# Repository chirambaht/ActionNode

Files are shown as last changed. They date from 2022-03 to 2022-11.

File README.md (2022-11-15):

# Action Tracer Node
This repository supports the Action Tracer project which I undertook as part of my Masters Dissertation at the University of Cape Town in 2021 - 2022.

## What is Action Tracer?
This project aims to create a motion capture system based on the MPU-6050 IMU. This system is powered by a Raspberry Pi Zero W, which collects, processes and sends data, in real time, to a users device. 

Action Tracer differs from most systes due to its use of a 6-axes IMU and it's promise to deliver 30 frames per second with minimal latency over a Wi-Fi network. 

To see more on this project, please visit the main repository: [Action Tracer](https://github.com/chirambaht/Action-Tracer).
## Why a node?
To monitor each articulating joint, an IMU needs to be placed near by to capture its rotation. To help this, the design houses two 20mm wide slots that allow a strap to go through it and strap it to the area it is montoring. At this stage, this design shows a wired node but future plans involve turning this node wireless. One such implementation of this was attempted and can be found here: [Wireless Action Node](https://github.com/chirambaht/WirelessAction).
## Bill of Materials
| Comment | Designator | Footprint | LCSC |
|---|---|---|---|
| 0.1u | C2,C5 | C_0603_1608Metric | C14663 |
| 2.2n | C3 | C_0603_1608Metric | C1604  |
| 0.33u | C4 | C_0603_1608Metric | C1615  |
| Power | D1,D2 | LED_0603_1608Metric | C2286  |
| MPU-6050 | U1 | InvenSense_QFN-24_4x4mm_P0.5mm | C24112 |
| 10k | R1,R2 | R_0603_1608Metric | C25804 |
| 68 | R3,R4 | R_0603_1608Metric | C27592 |
| 10n | C1 | C_0603_1608Metric | C57112 |
| AMS1117-3.3 | U2 | SOT-223-3_TabPin2 | C6186  |
## Images
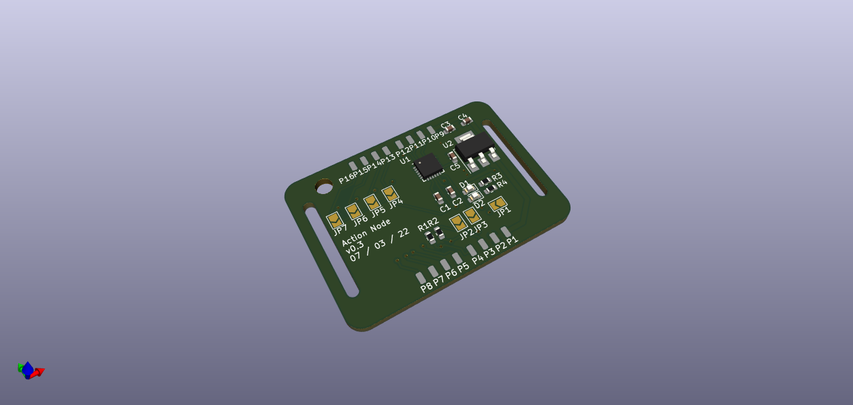
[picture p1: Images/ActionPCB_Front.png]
Front of the board The front of the Action Tracer Node.

A picture showing the front of the board. This will hold all the components used in this project. 
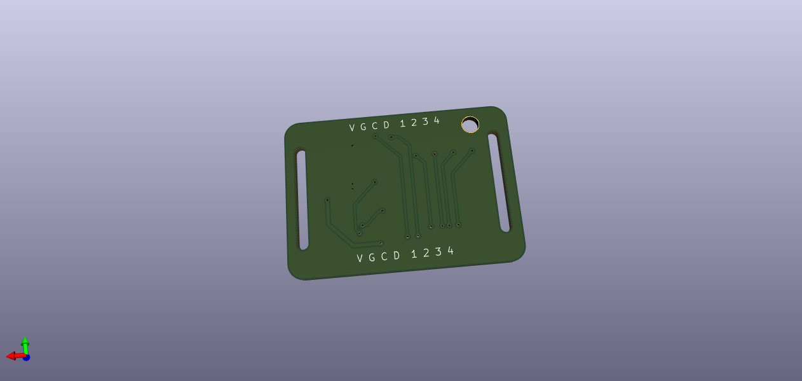
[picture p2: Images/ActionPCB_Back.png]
Back of the board The front of the Action Tracer Node.

The rear side of the board with markings for each of the connector lines, showing where they should be placed.
## Tools
This board was designed in KiCad 6.0.

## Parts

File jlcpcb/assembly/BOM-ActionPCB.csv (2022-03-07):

Comment | Designator | Footprint | LCSC
0.1u | C2,C5 | C_0603_1608Metric | C14663
2.2n | C3 | C_0603_1608Metric | C1604
0.33u | C4 | C_0603_1608Metric | C1615
Power | D1,D2 | LED_0603_1608Metric | C2286
MPU-6050 | U1 | InvenSense_QFN-24_4x4mm_P0.5mm | C24112
10k | R1,R2 | R_0603_1608Metric | C25804
68 | R3,R4 | R_0603_1608Metric | C27592
10n | C1 | C_0603_1608Metric | C57112
AMS1117-3.3 | U2 | SOT-223-3_TabPin2 | C6186
CH4 | P16 | SolderWirePad_1x01_SMD_1x2mm
CH3 | P15 | SolderWirePad_1x01_SMD_1x2mm
CH2 | P14 | SolderWirePad_1x01_SMD_1x2mm
CH1 | P13 | SolderWirePad_1x01_SMD_1x2mm
SDA | P12 | SolderWirePad_1x01_SMD_1x2mm
SCL | P11 | SolderWirePad_1x01_SMD_1x2mm
GND | P10 | SolderWirePad_1x01_SMD_1x2mm
VCC | P9 | SolderWirePad_1x01_SMD_1x2mm
CH4 | P8 | SolderWirePad_1x01_SMD_1x2mm
CH3 | P7 | SolderWirePad_1x01_SMD_1x2mm
CH2 | P6 | SolderWirePad_1x01_SMD_1x2mm
CH1 | P5 | SolderWirePad_1x01_SMD_1x2mm
SDA | P4 | SolderWirePad_1x01_SMD_1x2mm
SCL | P3 | SolderWirePad_1x01_SMD_1x2mm
GND | P2 | SolderWirePad_1x01_SMD_1x2mm
VCC | P1 | SolderWirePad_1x01_SMD_1x2mm
Jumper | JP7 | SolderJumper-2_P1.3mm_Open_TrianglePad1.0x1.5mm
Jumper | JP6 | SolderJumper-2_P1.3mm_Open_TrianglePad1.0x1.5mm
Jumper | JP5 | SolderJumper-2_P1.3mm_Open_TrianglePad1.0x1.5mm
Jumper | JP4 | SolderJumper-2_P1.3mm_Open_TrianglePad1.0x1.5mm
Jumper | JP3 | SolderJumper-2_P1.3mm_Open_TrianglePad1.0x1.5mm
Jumper | JP2 | SolderJumper-2_P1.3mm_Open_TrianglePad1.0x1.5mm
Jumper | JP1 | SolderJumper-2_P1.3mm_Open_TrianglePad1.0x1.5mm

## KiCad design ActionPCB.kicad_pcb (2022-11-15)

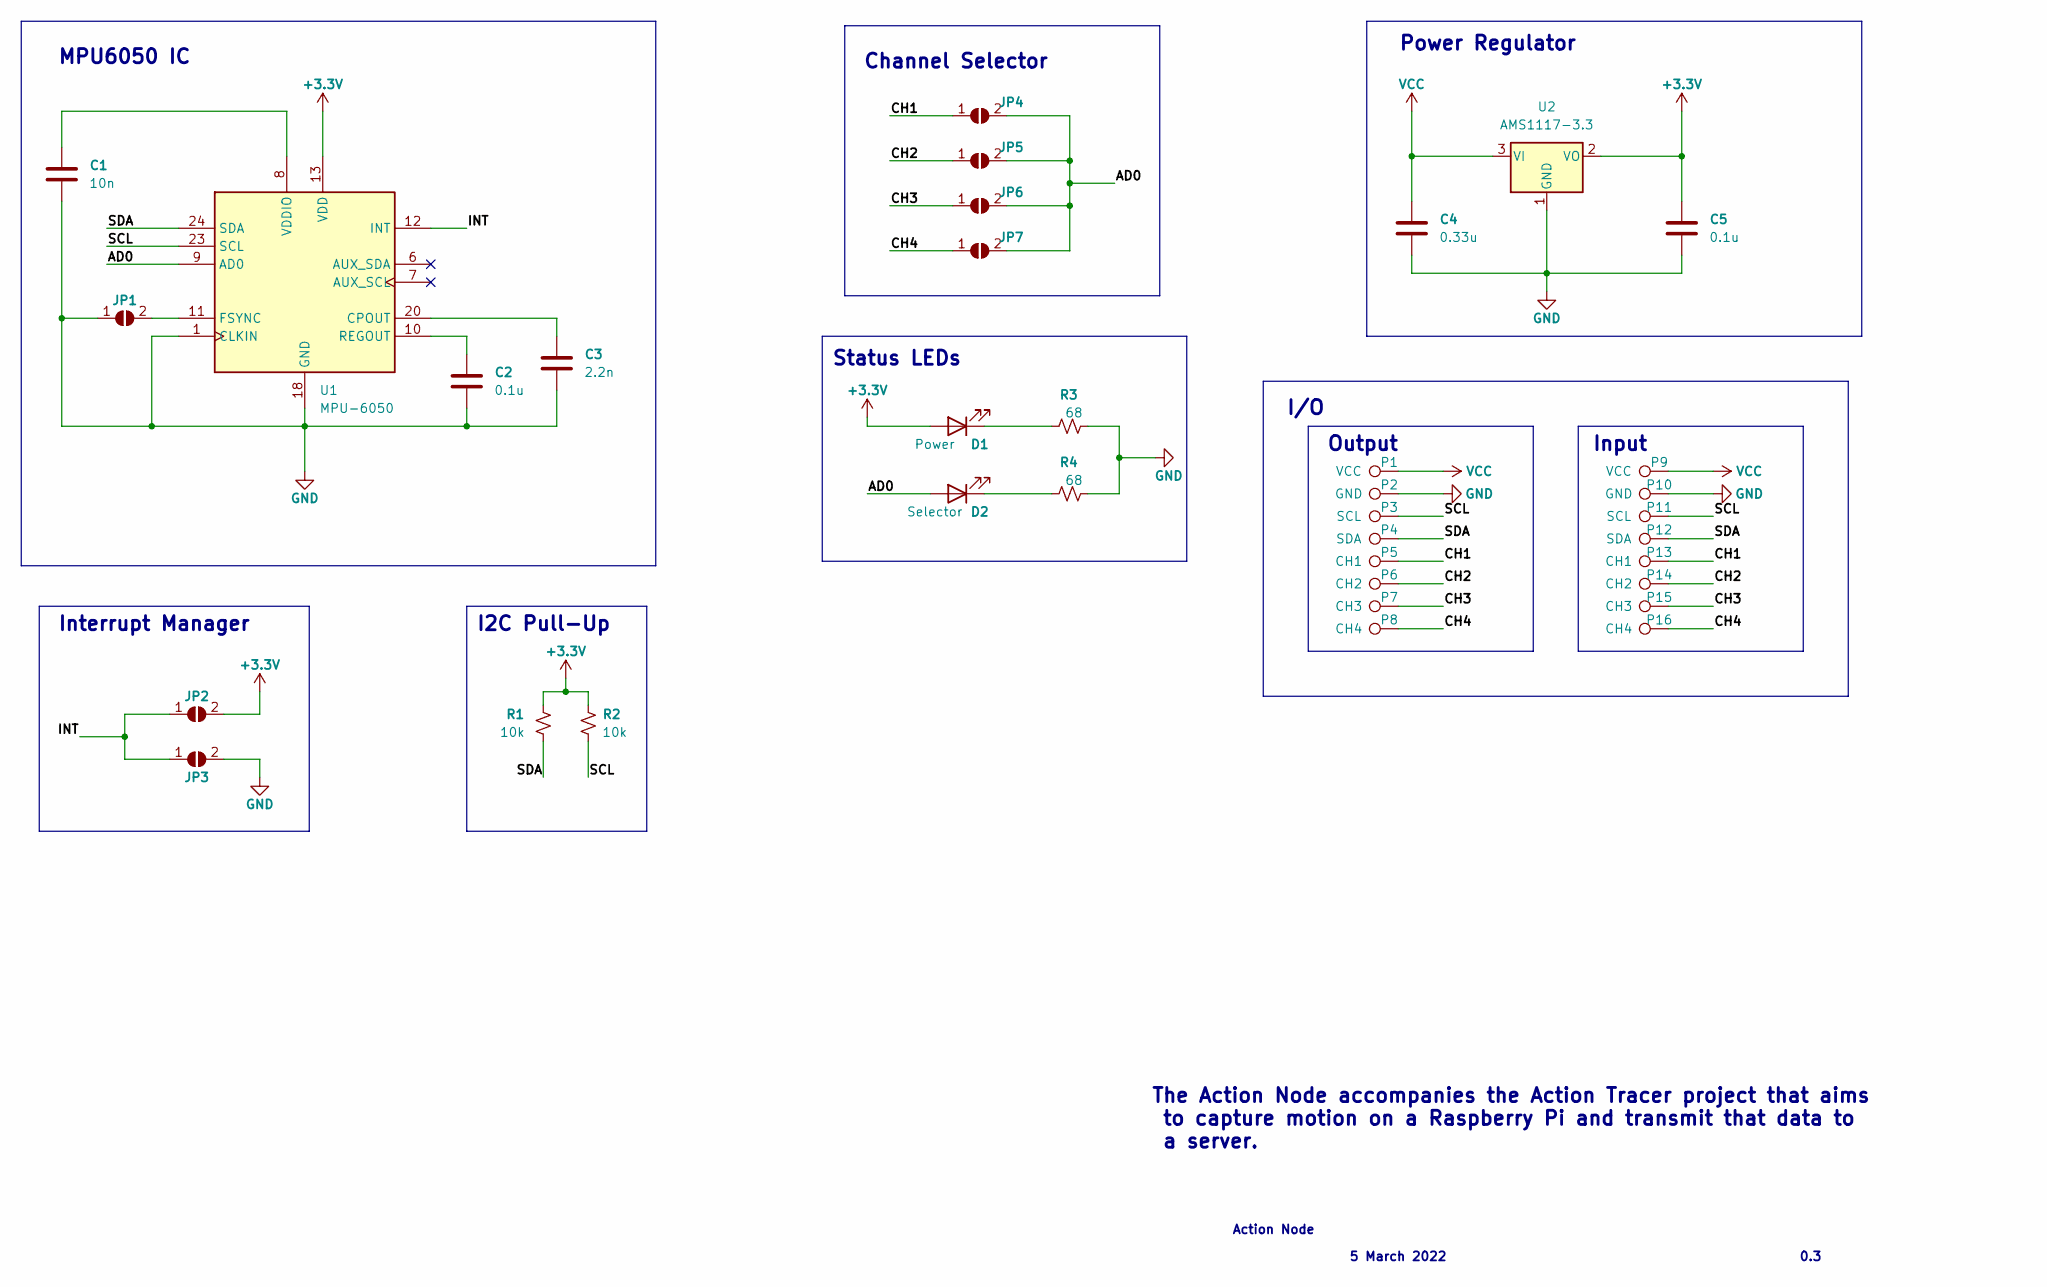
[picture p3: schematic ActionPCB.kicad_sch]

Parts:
C1: 10n; C_0603_1608Metric
C2, C5: 0.1u; C_0603_1608Metric
C3: 2.2n; C_0603_1608Metric
C4: 0.33u; C_0603_1608Metric
D1: Power; LED_0603_1608Metric
D2: Selector; LED_0603_1608Metric
JP1, JP2, JP3, JP4, JP5, JP6, JP7: Jumper; SolderJumper-2_P1.3mm_Open_TrianglePad1.0x1.5mm
P1, P9: VCC; SolderWirePad_1x01_SMD_1x2mm
P2, P10: GND; SolderWirePad_1x01_SMD_1x2mm
P3, P11: SCL; SolderWirePad_1x01_SMD_1x2mm
P4, P12: SDA; SolderWirePad_1x01_SMD_1x2mm
P5, P13: CH1; SolderWirePad_1x01_SMD_1x2mm
P6, P14: CH2; SolderWirePad_1x01_SMD_1x2mm
P7, P15: CH3; SolderWirePad_1x01_SMD_1x2mm
P8, P16: CH4; SolderWirePad_1x01_SMD_1x2mm
R1, R2: 10k; R_0603_1608Metric
R3, R4: 68; R_0603_1608Metric
U1: MPU-6050; InvenSense_QFN-24_4x4mm_P0.5mm
U2: AMS1117-3.3; SOT-223-3_TabPin2

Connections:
+3V3: C5.1, D1.2 (A), JP2.2 (B), R1.1, R2.1, U1.13 (VDD), U2.2 (VO)
/AD0: D2.2 (A), JP4.2 (B), JP5.2 (B), JP6.2 (B), JP7.2 (B), U1.9 (AD0)
/CH1: JP4.1 (A), P5.1, P13.1
/CH2: JP5.1 (A), P6.1, P14.1
/CH3: JP6.1 (A), P7.1, P15.1
/CH4: JP7.1 (A), P8.1, P16.1
/INT: JP2.1 (A), JP3.1 (A), U1.12 (INT)
/SCL: P3.1, P11.1, R2.2, U1.23 (SCL)
/SDA: P4.1, P12.1, R1.2, U1.24 (SDA)
GND: C1.2, C2.2, C3.2, C4.2, C5.2, JP1.1 (A), JP3.2 (B), P2.1, P10.1, R3.1, R4.1, U1.1 (CLKIN), U1.18 (GND), U2.1 (GND)
unnamed: C1.1, U1.8 (VDDIO)
unnamed: C2.1, U1.10 (REGOUT)
unnamed: C3.1, U1.20 (CPOUT)
unnamed: D1.1 (K), R3.2
unnamed: D2.1 (K), R4.2
unnamed: JP1.2 (B), U1.11 (FSYNC)
VCC: C4.1, P1.1, P9.1, U2.3 (VI)

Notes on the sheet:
I2C Pull-Up
Status LEDs
I/O
Output
Power Regulator
Action Node
Channel Selector
5 March 2022
MPU6050 IC
The Action Node accompanies the Action Tracer project that aims to capture motion on a Raspberry Pi and transmit that data to a server.
0.3
Input
Interrupt Manager

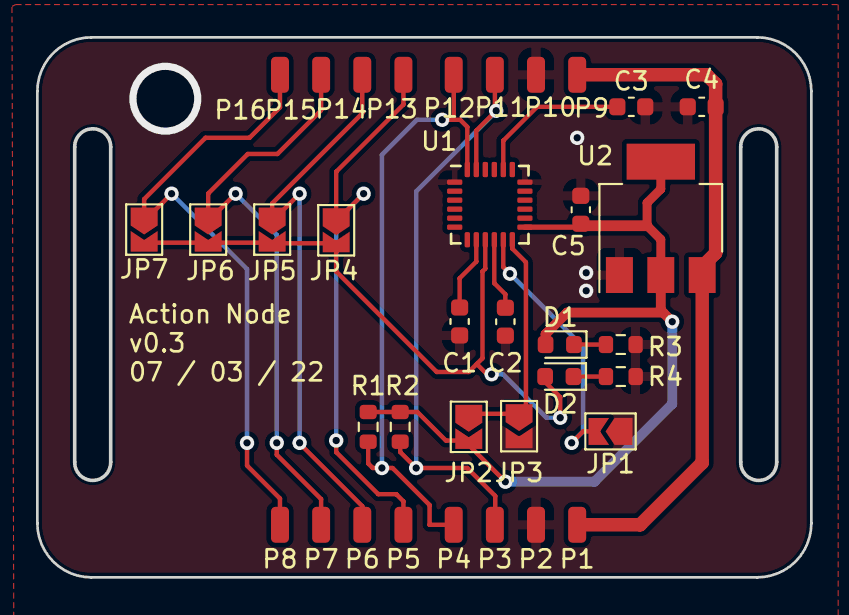
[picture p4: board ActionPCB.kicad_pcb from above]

Board: 2 copper layers, 43.0 x 30.0 mm, 36 parts (0 on the bottom side), 17 nets.

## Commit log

2022-03-07 Almost complete
    [ActionPCB-CuBottom.gbr, ActionPCB-CuTop.gbr, ActionPCB-EdgeCuts.gbr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]
2022-03-07 Final board single
    [ActionPCB.kicad_pcb, ActionPCB.kicad_sch]
2022-03-07 Ready for panelization
    [ActionPCB-CuBottom.gbr, ActionPCB-CuTop.gbr, ActionPCB-EdgeCuts.gbr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]
2022-03-15 Completed pricy board
    [ActionPCB-B_Cu.gbr, ActionPCB-B_Mask.gbr, ActionPCB-B_Silkscreen.gbr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]
2022-11-15 Updated repo documentation
    [ActionPCB.kicad_pcb]
